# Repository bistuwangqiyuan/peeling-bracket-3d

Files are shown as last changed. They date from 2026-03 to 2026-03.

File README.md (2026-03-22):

# 管道防腐层胶带剥离支架 — 3D 展示

基于 Three.js 的浏览器端 3D 模型（`index.html`）。

## GitHub

仓库：<https://github.com/bistuwangqiyuan/peeling-bracket-3d>

```bash
git add .
git commit -m "更新模型"
git push origin master
```

## Netlify 部署（连接 GitHub）

1. 登录 [Netlify](https://app.netlify.com/)，用 GitHub 授权。
2. **Add new site** → **Import an existing project** → 选 **GitHub**。
3. 选中仓库 `peeling-bracket-3d`。
4. 构建设置：
   - **Build command**：留空（无构建步骤）
   - **Publish directory**：`.`（根目录，与 `netlify.toml` 一致）
5. 点击 **Deploy site**。完成后会得到 `https://随机名.netlify.app`，可在 **Site settings → Domain management** 里改子域名或绑定自定义域名。

### 可选：Netlify CLI 本地上传

```bash
npm i -g netlify-cli
netlify login
netlify deploy --prod --dir=.
```

## 本地预览

用任意静态服务器打开目录，或直接双击 `index.html`（部分浏览器对 ES 模块有限制，建议用本地服务器）。

```bash
npx serve .
```

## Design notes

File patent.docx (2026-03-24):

# 说 明 书

## 一种管道防腐层胶带剥离强度测试用移动支架

## 技术领域

[0001]本实用新型涉及管道防腐检测技术领域，具体涉及一种用于管道防腐层胶带剥离强度测试的可移动支架装置。

## 背景技术

[0002]在石油、天然气、化工等行业中，埋地钢质管道的外防腐层是保障管道安全运行的重要屏障。防腐层常采用聚乙烯胶带、环氧煤沥青胶带、聚丙烯纤维胶带等缠绕型材料，其与管体基材之间的粘结强度直接影响防腐层的服役寿命和防护效果。依据GB/T 23257-2017《埋地钢质管道聚乙烯防腐层》、SY/T 0414-2017《钢质管道聚乙烯胶粘带防腐层技术标准》等国家和行业标准，在管道防腐施工验收和运行维护阶段，需对防腐层胶带进行剥离强度试验，以评价防腐层与管体之间的粘附质量。

[0003]现有的防腐层剥离试验多采用手动操作方式进行，即操作人员使用弹簧测力计或简易的手持式拉力计，沿管道轴向或周向方向手动牵拉预切割的胶带条，同时读取拉力值。这种传统方式存在以下不足：

[0004]第一，人工操作施加的拉力不均匀、不连续，拉伸速度难以恒定控制，导致测试结果重复性差、离散度大，测量数据的可靠性和客观性不足，难以满足标准对试验条件一致性的要求。

[0005]第二，操作人员在管道敷设现场（尤其是沟槽内、高处或狭小空间）进行手动拉伸试验时，身体姿势受限，难以保持稳定的施力方向和恒定的剥离角度，测试的标准化程度低。

[0006]第三，现有试验装置多为固定式台架结构，体积大、质量重，难以在管道施工现场灵活移动和快速定位，尤其在长距离管线的多点抽检作业中，搬运和安装效率极低。

[0007]第四，常见的试验设备一次仅能完成单条胶带试样的剥离测试，在需要同时对比测试多个试样或进行多通道平行试验时，效率低、耗时长。

[0008]第五，现有装置的力值加载机构和力值传感检测系统缺乏有效集成，力传感器的安装位置不合理、信号传输不便，影响了力值测量精度和数据采集的实时性。

[0009]综上所述，现有技术迫切需要一种结构紧凑、可自由移动、能自动施加恒定剥离力、支持双通道同时测试、并可精确采集剥离力数据的管道防腐层胶带剥离试验用支架装置。

## 实用新型内容

[0010]本实用新型的目的在于提供一种管道防腐层胶带剥离强度测试用移动支架，以解决现有技术中剥离试验装置不能移动、施力不均匀、测试效率低、测量精度差的技术问题。

[0011]为实现上述目的，本实用新型提供如下技术方案：

[0012]一种管道防腐层胶带剥离强度测试用移动支架，包括底座框架1、立柱8、顶部框架9、顶部横梁11、电动推杆13、力传感器20、钳形夹具25和支撑轮29。

[0013]所述底座框架1为矩形框架结构，由3030铝型材拼装而成，长度为600mm，宽度为120mm。底座框架1包括沿长度方向平行设置的前底座型材2和后底座型材3，以及沿宽度方向连接前底座型材2和后底座型材3的左横撑4和右横撑5，左横撑4位于底座框架1的左端，右横撑5位于底座框架1的右端。在底座框架1的中部区域，还设有沿宽度方向平行设置的推杆支撑型材6和推杆支撑型材7，二者间距为50mm，位于底座框架1的中央位置，用于支撑和固定电动推杆13的底部。前底座型材2、后底座型材3、左横撑4、右横撑5、推杆支撑型材6和推杆支撑型材7均采用截面尺寸为30mm×30mm的标准3030铝型材，通过铝型材专用连接件和角码10相互固定连接。

[0014]所述立柱8共四根，分别竖直设置于底座框架1的四个角部，采用与底座框架1相同规格的3030铝型材。每根立柱8的高度为270mm，底端与底座框架1的角部通过角码10螺栓连接，顶端与顶部框架9通过角码10螺栓连接。四根立柱8使底座框架1与顶部框架9之间形成一个高度为300mm的空间框架结构。

[0015]所述顶部框架9的结构与底座框架1类似，为矩形框架结构，由长度方向的两根600mm长型材和宽度方向的两根横撑组成，采用相同规格的3030铝型材。顶部框架9通过角码10与四根立柱8的顶端固定连接，形成完整的长方体空间框架。

[0016]所述角码10为L形钣金件，设有螺栓安装孔，用于连接相邻的两根铝型材。底座框架1与立柱8的连接处设有四个角码10，顶部框架9与立柱8的连接处设有四个角码10，共计八个角码10。

[0017]所述顶部横梁11设置于顶部框架9的上方，沿长度方向水平设置。顶部横梁11采用铝合金板材制成，长度为500mm，宽度为30mm，厚度为10mm。顶部横梁11沿其长度方向的中心线上，以20mm的等间距排列有多个横梁安装孔12，每个横梁安装孔12的直径为6mm，为通孔结构。横梁安装孔12用于挂装剥离线23和调整剥离测试点的位置。顶部横梁11通过螺栓固定于顶部框架9的顶面中央位置，横梁两端对称地超出底座框架1的两侧。

[0018]所述电动推杆13竖直安装于底座框架1的中央区域，位于推杆支撑型材6和推杆支撑型材7之间。电动推杆13为L型折返式结构，包括推杆底板14、驱动电机15、肘部连接件16、推杆主体17、伸缩杆18和推杆连接销19。

[0019]所述推杆底板14为矩形铝合金板，尺寸为60mm×80mm，水平固定于推杆支撑型材6和推杆支撑型材7的上表面，通过四颗螺栓紧固。推杆底板14的上表面安装有驱动电机15。

[0020]所述驱动电机15为直流电动机，水平安装于推杆底板14上，电机轴线沿支架宽度方向（前后方向）设置。驱动电机15的外壳为圆筒形，直径约36mm，长度约77mm，两端设有端盖。驱动电机15的一端伸出有输出轴，通过减速机构与推杆主体17内部的丝杠传动机构连接。

[0021]所述肘部连接件16为矩形钣金折弯件，连接驱动电机15的顶部与推杆主体17的底部，实现从水平方向到竖直方向的过渡转折，使电动推杆13整体呈L型结构布局。这种L型折返式结构使得驱动电机15水平布置在底座框架1内部空间中，有效降低了电动推杆13的总高度，使整个支架结构更加紧凑。

[0022]所述推杆主体17为矩形截面的铝合金壳体，截面尺寸为36mm×36mm，高度为130mm，竖直设置。推杆主体17内部装有丝杠螺母传动副，通过驱动电机15的旋转驱动实现伸缩杆18的直线往复运动。推杆主体17的上下两端设有端盖和法兰，中部设有加强环。

[0023]所述伸缩杆18为圆柱形不锈钢杆，直径为12mm，从推杆主体17的顶端伸出，可在驱动电机15的驱动下沿竖直方向做直线伸缩运动。伸缩杆18的顶端设有连接头，连接头上开有水平方向的横向通孔，用于安装推杆连接销19。

[0024]所述推杆连接销19为销轴，水平穿过伸缩杆18顶端的连接头，用于将伸缩杆18与顶部横梁11或被测试样的加载点铰接连接。当驱动电机15通电工作时，伸缩杆18向上伸出，推动顶部横梁11向上运动，从而通过剥离线23对被测胶带试样28施加向上的剥离拉力。

[0025]所述力传感器20共两个，分别设置于顶部横梁11的下方，对称布置于横梁中心线的两侧，间距为240mm。每个力传感器20为椭圆形外壳的小型称重传感器，通过传感器连接螺栓21安装于剥离线23上。力传感器20的上端通过传感器连接螺栓21与剥离线23的上段连接，下端通过传感器连接螺栓21与剥离线23的下段连接，使力传感器20串联在剥离力的传力路径上。每个力传感器20引出有传感器信号线22，用于将力值电信号传输至外部的数据采集仪或显示仪表。

[0026]所述剥离线23共两根，为金属钢丝绳或金属拉杆，直径约3.6mm。每根剥离线23的上端通过横梁悬挂点24悬挂于顶部横梁11上，中段串联有力传感器20，下段与钳形夹具25连接。剥离线23是将电动推杆13产生的向上推力传递至被测胶带试样28的力传递构件。

[0027]所述横梁悬挂点24为顶部横梁11上选定的某一横梁安装孔12的位置。由于横梁安装孔12沿横梁长度方向以20mm的间距均匀分布，操作者可根据被测管道的管径和试验位置需求，选择不同的横梁安装孔12作为横梁悬挂点24，从而灵活调整两条剥离线23之间的间距，适应不同尺寸管道的测试需求。

[0028]所述钳形夹具25共两个，分别安装于两根剥离线23的下端。每个钳形夹具25包括夹具本体、夹具钳口26和调节旋钮27。夹具钳口26为相对设置的两片金属钳板，钳口的夹持宽度约为20mm，钳口内表面设有防滑纹路，用于可靠夹持被测胶带试样28的自由端。调节旋钮27位于钳形夹具25的侧面，通过旋转调节旋钮27可调节夹具钳口26的开合程度和夹紧力大小，以适应不同厚度的胶带试样。

[0029]所述被测胶带试样28为从管道防腐层表面预切割的胶带条带，宽度通常为20mm～30mm，长度根据标准要求确定。被测胶带试样28的一端仍粘贴于管道表面（即粘结端），另一端为自由端，被夹持于钳形夹具25的夹具钳口26中。

[0030]所述支撑轮29共四个，分别设置于底座框架1四个角部的下方。每个支撑轮29包括轮架安装板30、轮叉31和轮轴32。轮架安装板30为矩形金属板，通过四颗螺栓固定于底座框架1角部对应的底面位置。轮叉31从轮架安装板30的下方延伸，呈U形结构，轮叉31的两臂之间安装有轮轴32。轮轴32上装有橡胶包覆的滚轮，滚轮直径为36mm。每个支撑轮29组件的总高度为62mm。四个支撑轮29的滚轮轴线均沿支架宽度方向设置，使滚轮可沿支架长度方向滚动行走，从而实现整个支架在管道上方沿管道轴向方向的移动定位功能。

[0031]本实用新型的有益效果在于：

[0032]第一，通过电动推杆13驱动，可自动、连续、恒速地施加剥离拉力，克服了人工操作力值不均匀、速度不稳定的缺陷，显著提高了剥离试验的重复性和数据可靠性。

[0033]第二，设置了四个支撑轮29，使整个支架可在管道上方沿管道轴向方向自由移动和定位，极大地方便了多点抽检作业，提高了现场试验效率。

[0034]第三，采用双通道测试结构，可同时对两条胶带试样进行平行剥离试验，测试效率提高一倍。

[0035]第四，顶部横梁11上设置多个等间距的横梁安装孔12，可灵活调整剥离线23的悬挂位置，适应不同管径管道的测试需求。

[0036]第五，力传感器20串联在剥离力传力路径上，可实时精确测量剥离力值，便于连接数据采集系统实现力值的实时记录和分析。

[0037]第六，整体框架采用3030铝型材拼装，结构轻便、拆装方便、模块化程度高，便于现场运输和组装。

[0038]第七，电动推杆13采用L型折返式结构，驱动电机15水平布置，有效降低了支架整体高度，使结构紧凑。

## 附图说明

[0039]图1是本实用新型的立体结构示意图；

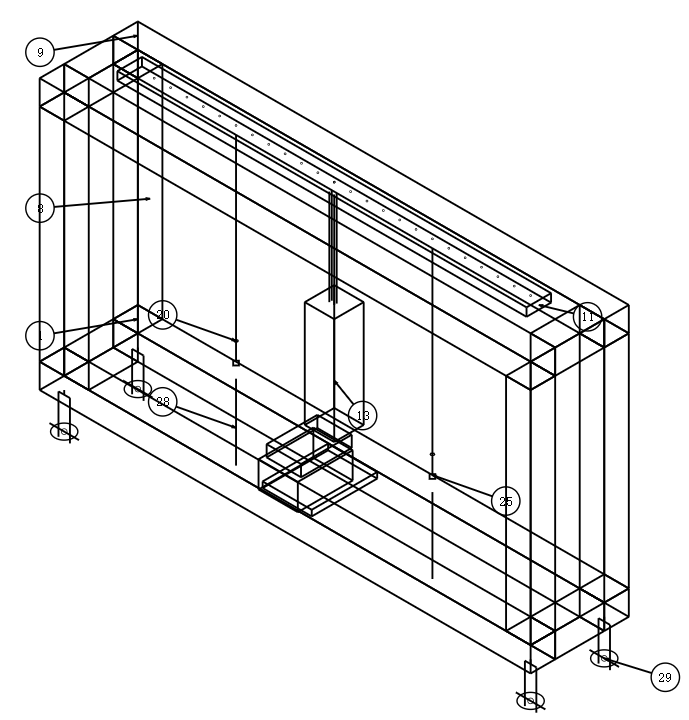
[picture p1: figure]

[0040]图2是本实用新型的主视图（前视图）；

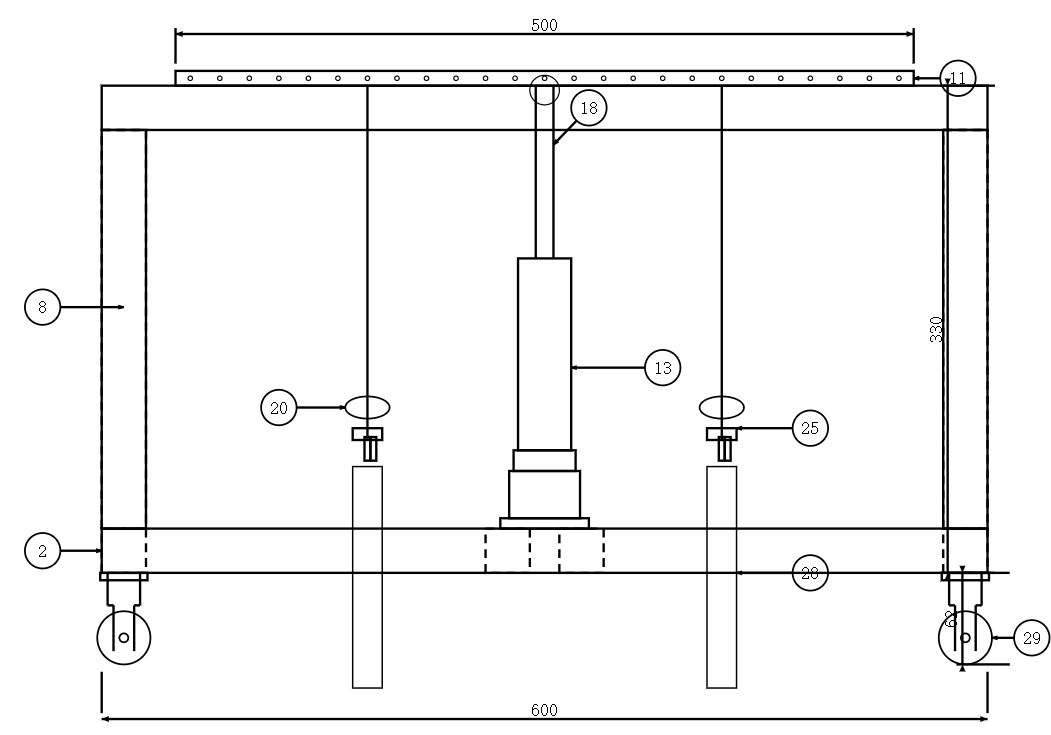
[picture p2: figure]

[0041]图3是本实用新型的左视图（侧视图）；

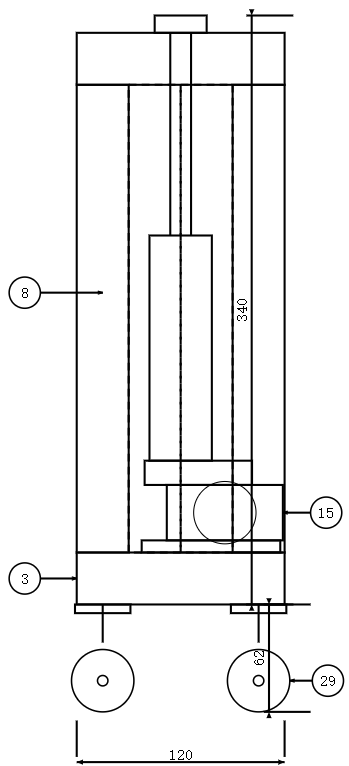
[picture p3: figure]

[0042]图4是本实用新型的俯视图（顶视图）；

[0043]图5是本实用新型中电动推杆的局部放大图；

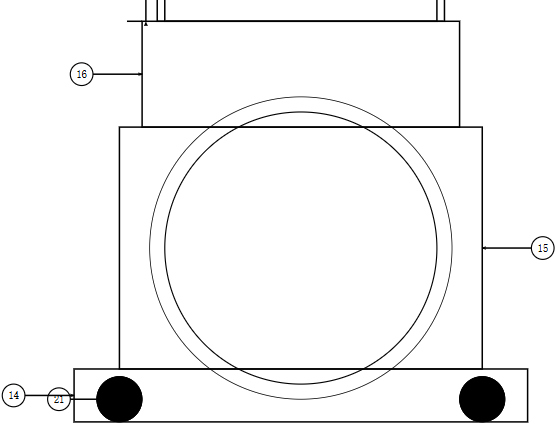
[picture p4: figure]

[0044]图6是本实用新型中钳形夹具与力传感器的局部放大图；

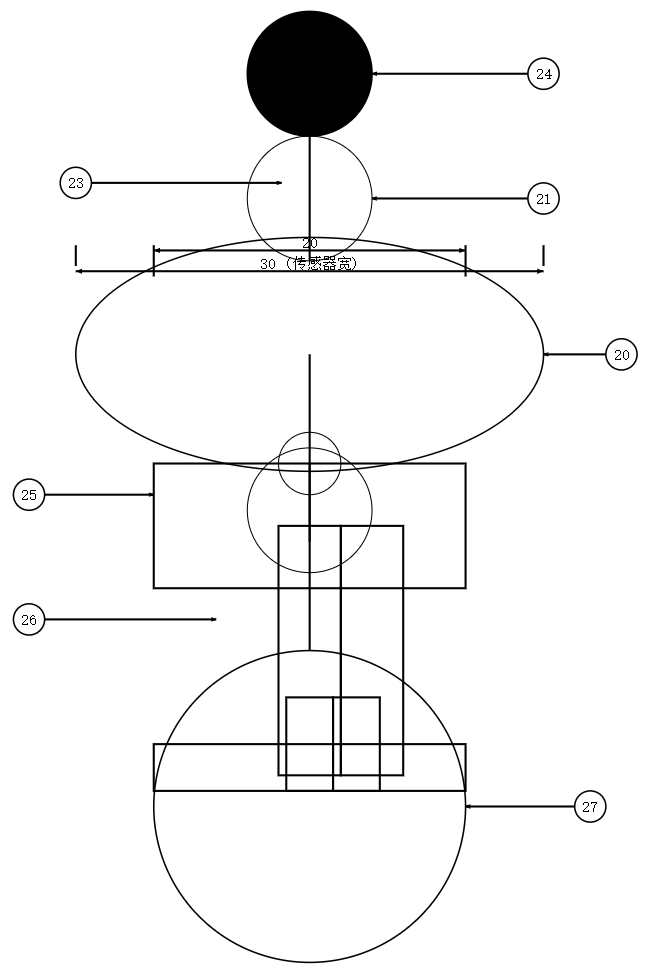
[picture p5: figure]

[0045]图7是本实用新型中支撑轮的局部放大图。

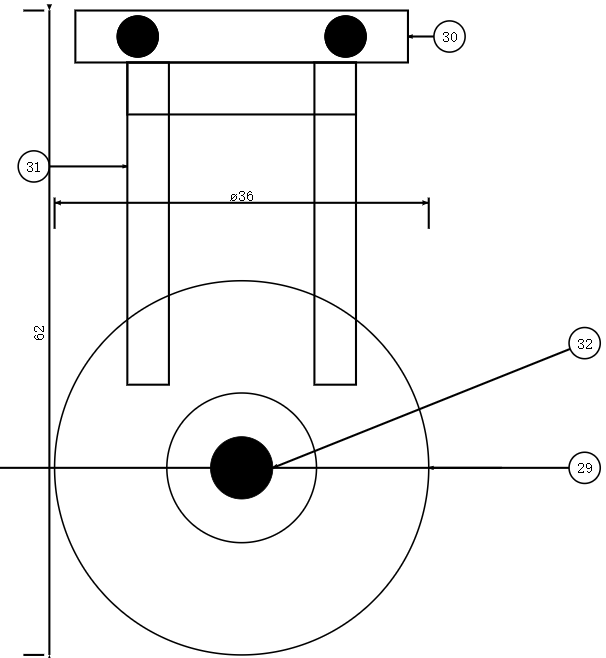
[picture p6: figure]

[0046]图中：1-底座框架，2-前底座型材，3-后底座型材，4-左横撑，5-右横撑，6-推杆支撑型材（左），7-推杆支撑型材（右），8-立柱，9-顶部框架，10-角码，11-顶部横梁，12-横梁安装孔，13-电动推杆，14-推杆底板，15-驱动电机，16-肘部连接件，17-推杆主体，18-伸缩杆，19-推杆连接销，20-力传感器，21-传感器连接螺栓，22-传感器信号线，23-剥离线，24-横梁悬挂点，25-钳形夹具，26-夹具钳口，27-调节旋钮，28-被测胶带试样，29-支撑轮，30-轮架安装板，31-轮叉，32-轮轴。

## 具体实施方式

[0047]下面结合附图和具体实施例对本实用新型作进一步的详细说明。

[0048]如图1至图7所示，本实用新型提供一种管道防腐层胶带剥离强度测试用移动支架，其整体结构由铝型材框架、电动推杆驱动系统、力值检测系统、试样夹持系统和移动行走系统五个功能模块组成。

[0049]一、铝型材框架的装配

[0050]如图1、图2和图3所示，首先装配底座框架1。取两根长度为600mm的3030铝型材作为前底座型材2和后底座型材3，沿长度方向平行放置，两者之间的中心距为90mm。取两根长度为60mm的3030铝型材分别作为左横撑4和右横撑5，沿宽度方向连接前底座型材2和后底座型材3的两端。同时在底座框架1的中部安装两根推杆支撑型材6和推杆支撑型材7，二者间距50mm。

[0051]接下来安装四根立柱8。取四根长度为270mm的3030铝型材，分别竖直安装于底座框架1的四个角部，使用L形角码10和M6螺栓进行连接固定。

[0052]然后装配顶部框架9，结构与底座框架1对称。将顶部框架9安装于四根立柱8的顶端。至此构成长600mm、宽120mm、高300mm的长方体空间框架。

[0053]二、电动推杆驱动系统的安装

[0054]如图2和图5所示，电动推杆13安装于底座框架1中央。推杆底板14水平固定于推杆支撑型材上。驱动电机15水平安装于推杆底板14上方，为12V或24V直流电动机。肘部连接件16实现90度过渡。推杆主体17竖直安装，内部装有丝杠传动副。伸缩杆18为直径12mm的不锈钢光杆。

[0055]三、顶部横梁的安装

[0056]如图1、图2和图4所示，顶部横梁11为500mm×30mm×10mm的铝合金板，沿中心线以20mm等间距钻有直径6mm的通孔。顶部横梁11中心位置通过推杆连接销19与伸缩杆18铰接连接。

[0057]四、力值检测系统的安装

[0058]如图2和图6所示，力传感器20为小型称重传感器，外壳呈椭圆形。两个力传感器20分别串联在两条剥离线23上，对称布置，可独立工作实现双通道并行测量。

[0059]五、试样夹持系统的安装

[0060]如图2和图6所示，钳形夹具25包括夹具本体、夹具钳口26和调节旋钮27。钳口宽度约20mm，内表面有防滑纹路。旋转调节旋钮27可调节夹紧力。

[0061]六、移动行走系统的安装

[0062]如图2、图3和图7所示，四个支撑轮29安装于底座框架1四角下方。轮架安装板30通过螺栓固定，轮叉31呈U形，轮轴32上套装橡胶滚轮（直径36mm）。总高度62mm，滚轮轴线沿宽度方向使支架可沿长度方向行走。

[0063]七、工作原理

[0064]使用时，将支架置于管道上方工作面上，推动至待测位置。在管道防腐层表面预切割两条胶带试样，夹持于左右两个钳形夹具25中。选择合适的横梁安装孔12作为悬挂点。接通电源启动电动推杆13，伸缩杆18向上推动横梁，通过剥离线23拉伸试样使其从管道表面逐渐剥离。力传感器20持续检测剥离力值。试验完成后可推动支架至下一测试点继续测试。

# 权 利 要 求 书

1. 一种管道防腐层胶带剥离强度测试用移动支架，其特征在于，包括：底座框架（1），所述底座框架（1）为由3030铝型材拼装而成的矩形框架结构，包括沿长度方向平行设置的前底座型材（2）和后底座型材（3），以及沿宽度方向连接所述前底座型材（2）和后底座型材（3）两端的左横撑（4）和右横撑（5）；立柱（8），所述立柱（8）共四根，分别竖直设置于所述底座框架（1）的四个角部，通过角码（10）与所述底座框架（1）连接；顶部框架（9），设置于四根所述立柱（8）的顶端，与所述底座框架（1）和所述立柱（8）共同构成长方体空间框架；顶部横梁（11），水平设置于所述顶部框架（9）的上方，沿长度方向延伸，所述顶部横梁（11）上设有多个横梁安装孔（12）；电动推杆（13），竖直安装于所述底座框架（1）的中央区域，其伸缩杆（18）的顶端与所述顶部横梁（11）连接；剥离线（23），至少两根，各所述剥离线（23）的上端通过横梁悬挂点（24）悬挂于所述顶部横梁（11）上；力传感器（20），各所述剥离线（23）上分别串联有一个所述力传感器（20）；钳形夹具（25），各所述剥离线（23）的下端分别连接有一个所述钳形夹具（25），用于夹持被测胶带试样（28）；支撑轮（29），共四个，分别设置于所述底座框架（1）四个角部的下方，所述支撑轮（29）的滚轮轴线沿支架宽度方向设置，使所述移动支架可沿支架长度方向滚动行走。

2. 根据权利要求1所述的移动支架，其特征在于，所述底座框架（1）的中央区域还设有沿宽度方向平行设置的推杆支撑型材（6）和推杆支撑型材（7），用于支撑和固定所述电动推杆（13）的推杆底板（14）。

3. 根据权利要求1所述的移动支架，其特征在于，所述电动推杆（13）为L型折返式结构，包括水平设置的驱动电机（15）、连接所述驱动电机（15）顶部与推杆主体（17）底部的肘部连接件（16），以及竖直设置的所述推杆主体（17）和从所述推杆主体（17）顶端伸出的所述伸缩杆（18）。

4. 根据权利要求1所述的移动支架，其特征在于，所述顶部横梁（11）采用铝合金板材制成，长度为500mm，宽度为30mm，厚度为10mm，所述多个横梁安装孔（12）以20mm的等间距排列，每个所述横梁安装孔（12）的直径为6mm。

5. 根据权利要求1所述的移动支架，其特征在于，所述力传感器（20）为椭圆形外壳的称重传感器，其上端和下端分别通过传感器连接螺栓（21）与所述剥离线（23）连接，每个所述力传感器（20）引出有传感器信号线（22）。

6. 根据权利要求1所述的移动支架，其特征在于，所述钳形夹具（25）包括夹具本体、相对设置的两片夹具钳口（26）和调节旋钮（27），所述夹具钳口（26）内表面设有防滑纹路。

7. 根据权利要求1所述的移动支架，其特征在于，所述支撑轮（29）包括轮架安装板（30）、轮叉（31）和轮轴（32），所述轮架安装板（30）通过螺栓固定于所述底座框架（1）角部的底面，所述轮叉（31）呈U形，所述轮轴（32）上安装有橡胶包覆的滚轮。

8. 根据权利要求7所述的移动支架，其特征在于，所述支撑轮（29）的总高度为62mm，所述滚轮的直径为36mm。

9. 根据权利要求1所述的移动支架，其特征在于，所述底座框架（1）的长度为600mm，宽度为120mm，所述立柱（8）的高度为270mm。

10. 根据权利要求1所述的移动支架，其特征在于，所述伸缩杆（18）的顶端设有连接头，所述连接头上设有横向通孔，所述横向通孔内穿装有推杆连接销（19），用于将所述伸缩杆（18）与所述顶部横梁（11）铰接连接。

11. 根据权利要求1所述的移动支架，其特征在于，所述底座框架（1）、所述立柱（8）和所述顶部框架（9）均采用截面尺寸为30mm×30mm的3030铝型材，各所述铝型材之间通过L形角码（10）和螺栓连接固定。

12. 根据权利要求1所述的移动支架，其特征在于，所述剥离线（23）为两根，对称布置于所述顶部横梁（11）中心线的两侧，两根所述剥离线（23）的间距可通过选择不同的所述横梁安装孔（12）进行调节。

# 说 明 书 摘 要

本实用新型公开了一种管道防腐层胶带剥离强度测试用移动支架，属于管道防腐检测技术领域。该移动支架包括由3030铝型材拼装的底座框架、四根立柱、顶部框架、顶部横梁、电动推杆、力传感器、钳形夹具和支撑轮。电动推杆竖直安装于底座框架中央，采用L型折返式结构，通过伸缩杆与顶部横梁连接。顶部横梁上以等间距设置多个安装孔，供悬挂剥离线。两条剥离线上分别串联力传感器，下端各连接一个钳形夹具，用于夹持被测胶带试样。底座框架四角下方安装有四个支撑轮，使支架可沿管道轴向方向自由移动。本实用新型实现了管道防腐层胶带剥离试验的自动化施力、双通道并行测试、实时力值采集和灵活移动定位，显著提高了测试效率、数据可靠性和操作便捷性。

摘要附图：图1

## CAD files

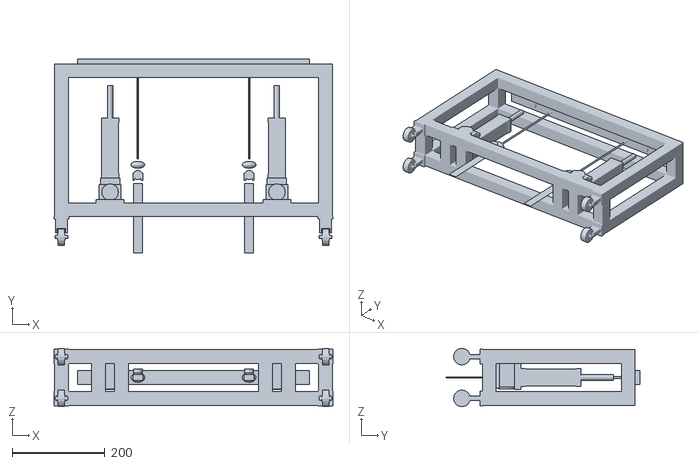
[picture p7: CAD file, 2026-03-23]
peeling-bracket.stl
602.0 x 418.0 x 126.0

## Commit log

2026-03-21 feat: pipe anti-corrosion tape peeling bracket 3D model
    Made-with: Cursor
2026-03-21 fix: sensor flush above clamp, brighter aluminum profiles
    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
2026-03-21 fix: rotate clamp 90deg so knob faces right
    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
2026-03-21 feat: add 2mm rounded corners to all 3030 profiles
    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
2026-03-21 feat: add standard view buttons (front, left, top)
    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
2026-03-21 feat: add lite/full frame toggle, default to lite version
    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
2026-03-21 feat: redesign actuator to L-shaped with rear motor and elbow
    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
2026-03-21 fix: extend actuator rod to contact top beam
    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
2026-03-21 fix: eliminate actuator body gap and motor floating issue
    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
2026-03-21 feat: extend motor length by 1/5 toward center
    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
2026-03-22 feat: collapse info panel and legend into toggle button
    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
2026-03-22 feat: 支撑轮、10mm横梁打孔、Netlify 配置与部署说明
    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
2026-03-22 feat: refactor single actuator to dual symmetric actuators
    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
2026-03-23 feat: 添加实用新型专利申请书与2D专利附图
    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
2026-03-23 feat: 修复立体图、新增纯净2D图纸、导航链接、专利docx文档
    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
2026-03-23 fix: 立体图补全所有12条棱边、改进轮组和推杆细节
    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
2026-03-23 feat: 新增管道爬车+剥离支架组合3D页面，更新所有页面导航链接
    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
2026-03-23 feat: 生成简化版剥离支架STL文件，添加下载按钮
    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
    [peeling-bracket.stl]
2026-03-23 fix: 支架与管道平行放置，爬车放大至300x300mm
    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
2026-03-23 fix: 组合页面改为单推杆支架
    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
2026-03-23 fix: 支架侧挂爬车、轨道改为2道200mm板型
    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
2026-03-23 fix: 爬车轮子改为周向滚动（轴线沿管道Z轴）
    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
2026-03-23 fix: 修正爬车轮位、支架坐标系、侧挂方向和加强肋
    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
2026-03-23 fix: 支架短边(120mm左侧面)连接爬车侧板，长边向外延伸
    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
2026-03-23 feat: 爬车改350x250x200mm，新增单推杆支架页面，互联链接
    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
2026-03-23 fix: 支架连接到爬车前侧面（+Z方向）
    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
2026-03-23 fix: 轨道间距70cm+D1280钢环，爬车偏右侧+转向架延伸
    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
2026-03-23 feat: 新增单推杆支架+爬车驱动盒页面(250x350x200mm)
    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
2026-03-24 fix: 爬车盒底面与支架底座框架齐平，消除空隙
    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
2026-03-24 fix: 管道页面只保留管道+轨道+圆环，去掉爬车和支架
    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
2026-03-24 fix: 去掉轨道上的D1280钢制圆环
    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
2026-03-24 feat: 增加D1280×2mm×W200mm钢制圆环套在管道外
    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
2026-03-24 feat: 新增单管道页面pipe.html，所有页面增加链接
    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
2026-03-24 feat: 重建装配管道组合页面=管道+轨道+圆环+支架爬车盒(管壁上方2cm)
    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
2026-03-24 fix: 支架爬车沿管道径向放置(600mm沿管道轴向)
    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
2026-03-24 fix: 外圆环增加齿轮槽(5mm宽×30mm深，间距20mm，约160齿)
    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
2026-03-24 fix: 外圆环增加齿轮槽(5mm宽×30mm深,间隔20mm,约160齿)
    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
2026-03-24 feat: 轨道间距增至80cm,外圆环改为2mm深长方形孔(5x30mm间隔10mm),爬车盒降低25mm,支撑轮贴合管面
    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
2026-03-24 fix: 修复爬车盒顶部圆柱体悬空,居中对齐到连接板上
    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
2026-03-24 feat: 新增正式爬车STEP模型页面,全站添加导航链接,部署脚本支持子目录
    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
2026-03-24 feat: 新增管道组合+正式爬车页面,爬车旋转90度贴合支架短边,添加导航链接
    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
2026-03-24 feat: 全站8个3D页面增加方向键控制视角旋转功能
    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
